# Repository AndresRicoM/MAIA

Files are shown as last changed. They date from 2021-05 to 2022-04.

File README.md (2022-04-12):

# MAIA

```
███╗   ███╗ █████╗ ██╗ █████╗
████╗ ████║██╔══██╗██║██╔══██╗
██╔████╔██║███████║██║███████║
██║╚██╔╝██║██╔══██║██║██╔══██║
██║ ╚═╝ ██║██║  ██║██║██║  ██║
╚═╝     ╚═╝╚═╝  ╚═╝╚═╝╚═╝  ╚═╝

. ,-"-.   ,-"-. ,-"-.   ,-"-. ,-"-.   ,
 X | | \ / | | X | | \ / | | X | | \ /
/ \| | |X| | |/ \| | |X| | |/ \| | |X|
   `-!-' `-!-"   `-!-' `-!-'   `-!-' `-

╔═╗┬┌┬┐┬ ┬  ╔═╗┌─┐┬┌─┐┌┐┌┌─┐┌─┐       ╔╦╗╦╔╦╗  ╔╦╗┌─┐┌┬┐┬┌─┐  ╦  ┌─┐┌┐
║  │ │ └┬┘  ╚═╗│  │├┤ ││││  ├┤   ───  ║║║║ ║   ║║║├┤  │││├─┤  ║  ├─┤├┴┐
╚═╝┴ ┴  ┴   ╚═╝└─┘┴└─┘┘└┘└─┘└─┘       ╩ ╩╩ ╩   ╩ ╩└─┘─┴┘┴┴ ┴  ╩═╝┴ ┴└─┘

```
Andres Rico - MIT Media Lab - aricom@mit.edu

Modular, low-cost, open source and portable bio reactor for bio sensor testing and deployment.

Ackowledgements:
Laura Gonzalez, Eyal Perry, David Kong, George Church, Joseph Jacobson.

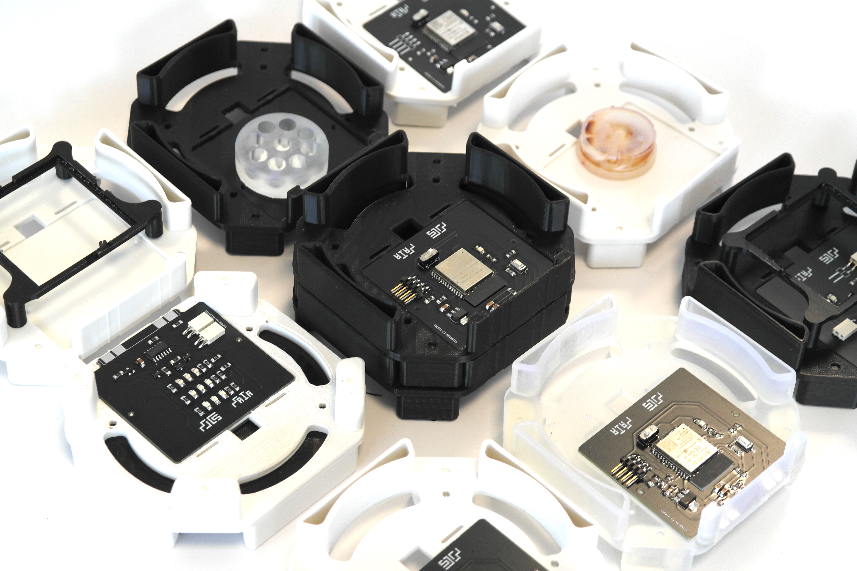
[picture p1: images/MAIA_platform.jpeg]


MAIA is a tool that inspires creativity by enhancing biosensor development for bottom-up citizen sensing applications.

The device is designed to be a tool that can allow for quick experimentation and testing of bio-sensor genetic circuits. The lab contributes to a growing ecosystem of the DIY-Bio movement. It provides a modular platform for experimental design and quick iteration based scientific development.

The device borrows characteristics from LEGO bricks to create easy to assemble and interchangeable components. Modules can be stacked and exchanged depending on function and experiment design. The project also integrates the vision of Arduino to motivate hacking and multi purpose use of the device. People can create modules and functionalities that are based on the main architecture design. The designs can be documented and distributed so that many have access to them. Lastly, the reactor brings to bio-reactor and bio-sensor development the benefits that mobile phones brought to computing.

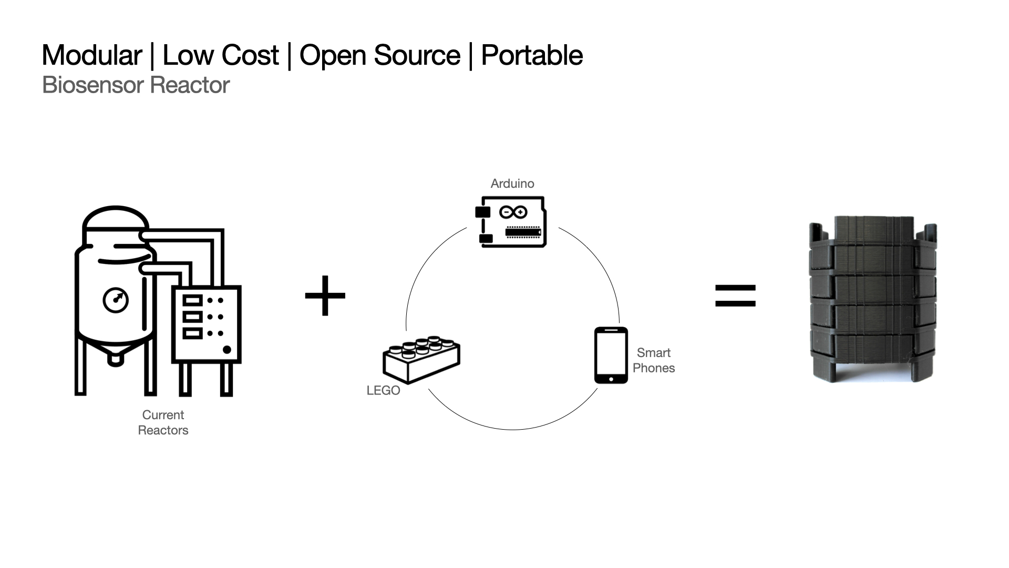
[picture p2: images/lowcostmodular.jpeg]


The device is easy to scale because its open source and low cost and can be used for multiple experiments as modules are created and designed specifically for each experiment. The current base structure allows for temperature, ventilation and light tuning.

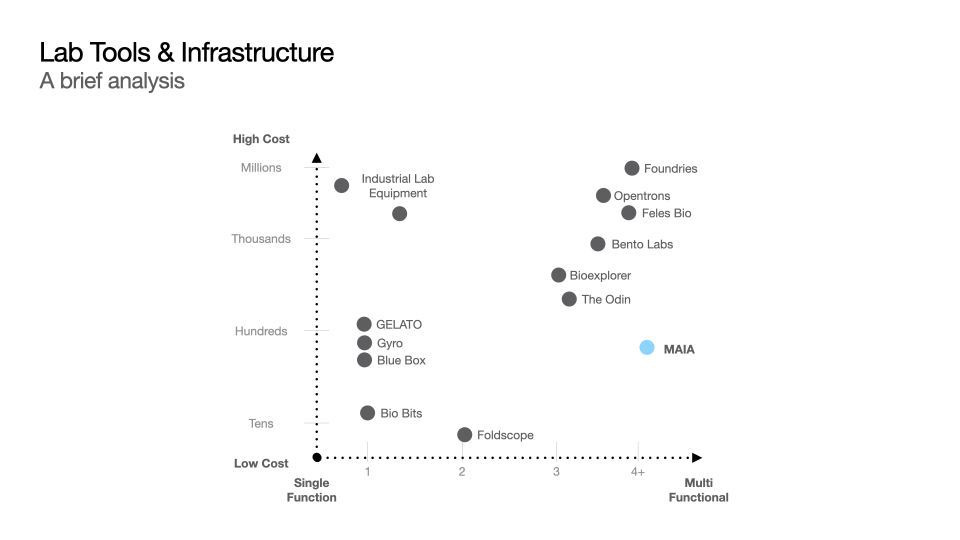
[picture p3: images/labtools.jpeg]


The device modularizes bio-reactor functions like, temperature and ventilation control to evaluate plasmid design and bio-sensing experiments. The top module of the device can be modified depending on the stimulation that we want to test. We can have experiments that stimulate cultures with sound, vibrations, light. 

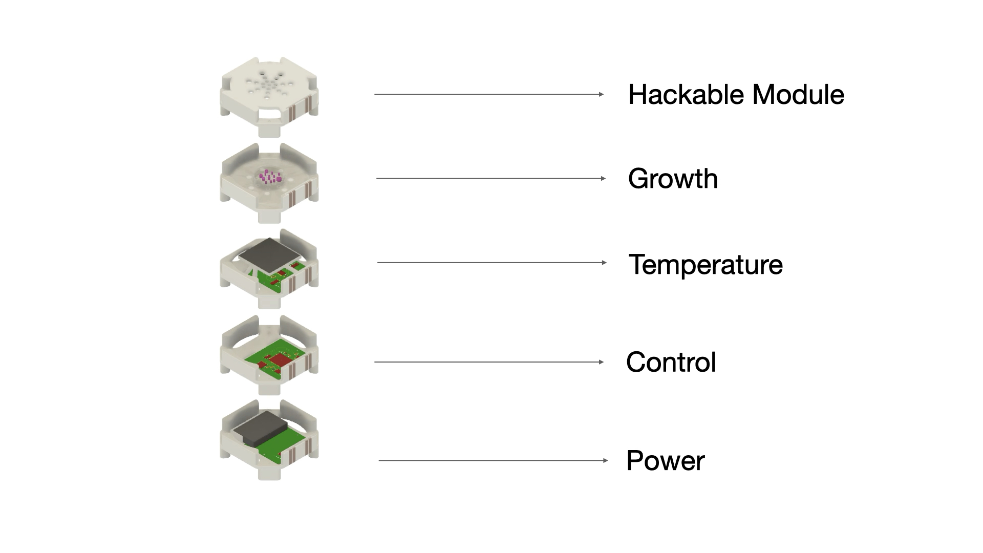
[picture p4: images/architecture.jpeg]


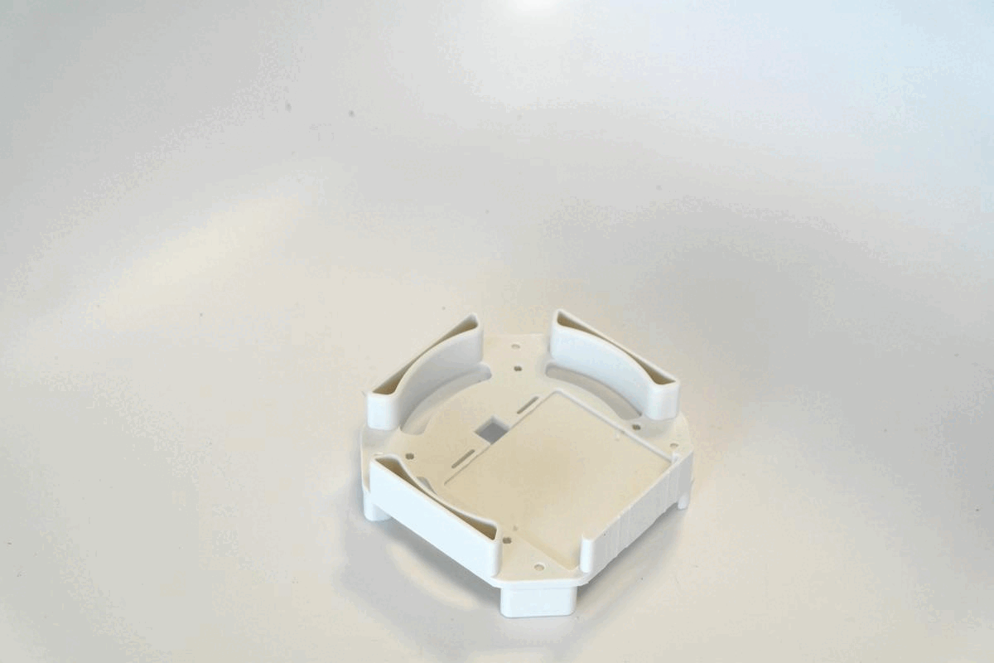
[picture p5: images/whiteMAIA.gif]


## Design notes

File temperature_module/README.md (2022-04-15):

MAIA Temperature Module

The module uses an epoxy thermistor and controls a peltier slip that is in contact with the bacterial culture.
The current version of the module only allows for heating up. The device cools down by deactivating the peltier and having the ambient temperature cool the device down. 

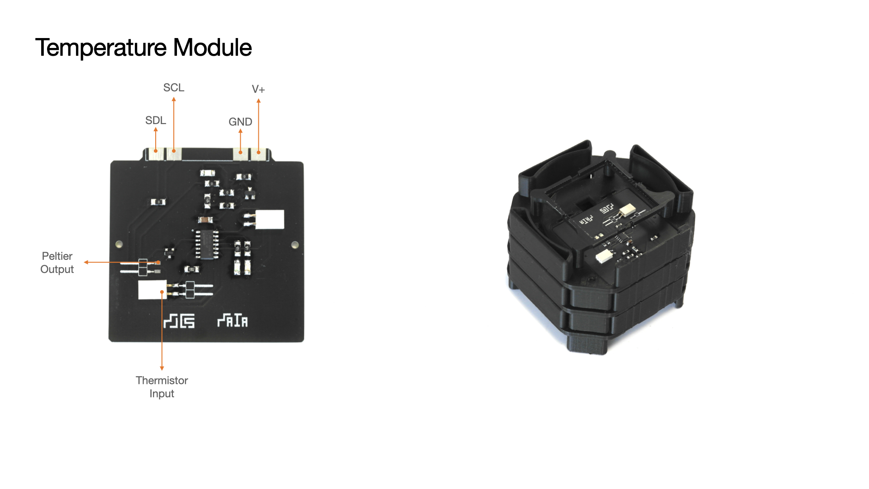
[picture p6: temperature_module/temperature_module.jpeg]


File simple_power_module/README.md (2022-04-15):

MAIA Power Module

The module connects to a 5V usb cable. It can also be used with Lipo batteries for portable operation.

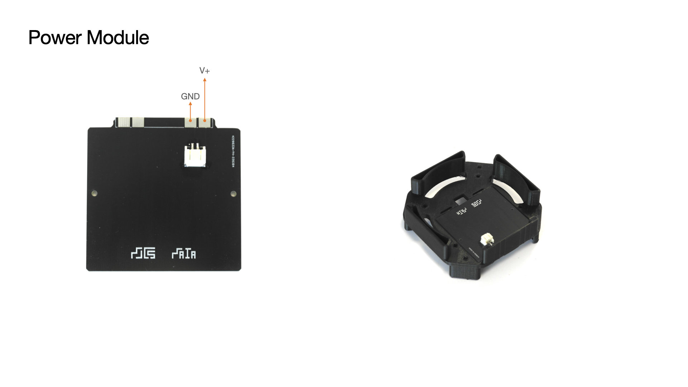
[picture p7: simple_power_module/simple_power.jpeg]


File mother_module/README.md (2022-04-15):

MAIA Mother Module

The Module enables WiFi and Bluetooth communication for the reactor. The module also controls messages sent to other modules and acts a central relay of infromation for the system.

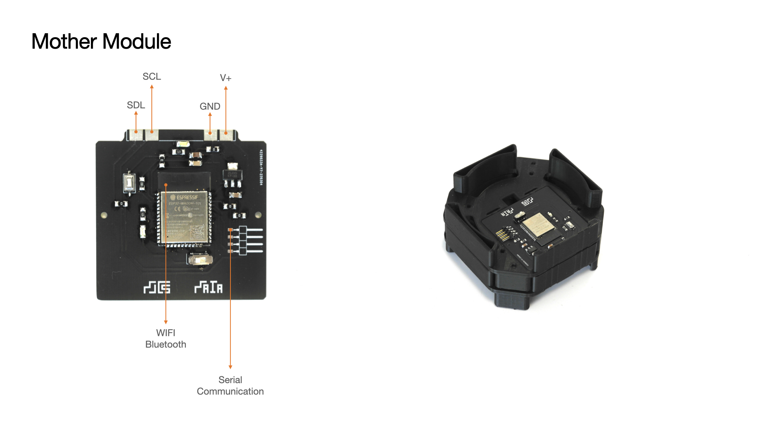
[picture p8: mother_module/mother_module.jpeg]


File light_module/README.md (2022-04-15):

MAIA Light Module

The Module can be used to stimulate bacteria in three different visible wavelengths (Red, Green, Blue).

It is important to note that the modules power anc communication lines are inverted because it is placed on the pcb slot that is at the lower section of the base module structure.

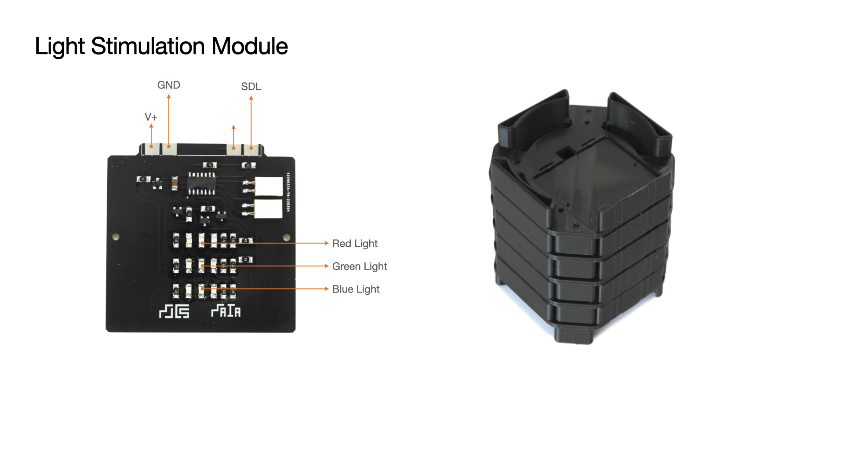
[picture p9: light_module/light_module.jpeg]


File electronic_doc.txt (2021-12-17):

Mother Board
I2C Address - 0

Temperature Board
Inputs - NTC Temperature Sensor
Outputs - Peltier, LED1, LED2

I2C Address - 3
Query with 1:
Returns Sensor and Peltier State

Query with 2:
Turns ON Peltier

Query with 3:
Turns OFF Peltier

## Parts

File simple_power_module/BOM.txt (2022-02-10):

- (1) JST Conn Header - S2B-PH-SM4-TB(LF)(SN)
- (1) JST Conn Header With Cable (Male)

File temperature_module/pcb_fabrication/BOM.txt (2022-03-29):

- (1) ATTINY 1614
- (5) 0 Ohm SMD 1206 Resistor
- (3) .5K SMD 1206 Resistor
- (1) 1uF SMD 1206 Capacitor
- (1) Green SMD LED
- (1) Blue SMD LED
- (1) Red SMD LED
- (1) 3.3V Regulator (ZLDO1117G33TA)
- (1) N Transistors
- (3) 2 pin Female horizontal headers
- (1) Peltier
- (1) NTC Epoxy Thermistor

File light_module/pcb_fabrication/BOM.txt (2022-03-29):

- (1) ATTINY 1614
- (7) 0 Ohm SMD 1206 Resistor
- (9) .5K SMD 1206 Resistor
- (1) 1uF SMD 1206 Capacitor
- (3) Green SMD LED (Best to only use 1 to not have heat problems)
- (3) Blue SMD LED
- (3) Red SMD LED
- (1) 3.3V Regulator (ZLDO1117G33TA)
- (3) N Transistors
- (2) 2 pin Female horizontal headers

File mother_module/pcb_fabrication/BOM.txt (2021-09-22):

- (1) ESP 32 WROOM
- (1) 10K SMD 1206 Resistor
- (2) .5K SMD 1206 Resistor
- (1) 1uF SMD 1206 Capacitor
- (1) .1uF SMD 1206 Capacitor
- (1) 10uF SMD 1206 Capacitor
- (1) Green SMD LED
- (1) Blue SMD LED
- (1) 3.3V Regulator (ZLDO1117G33TA)
- (1) Switch
- (1) Button

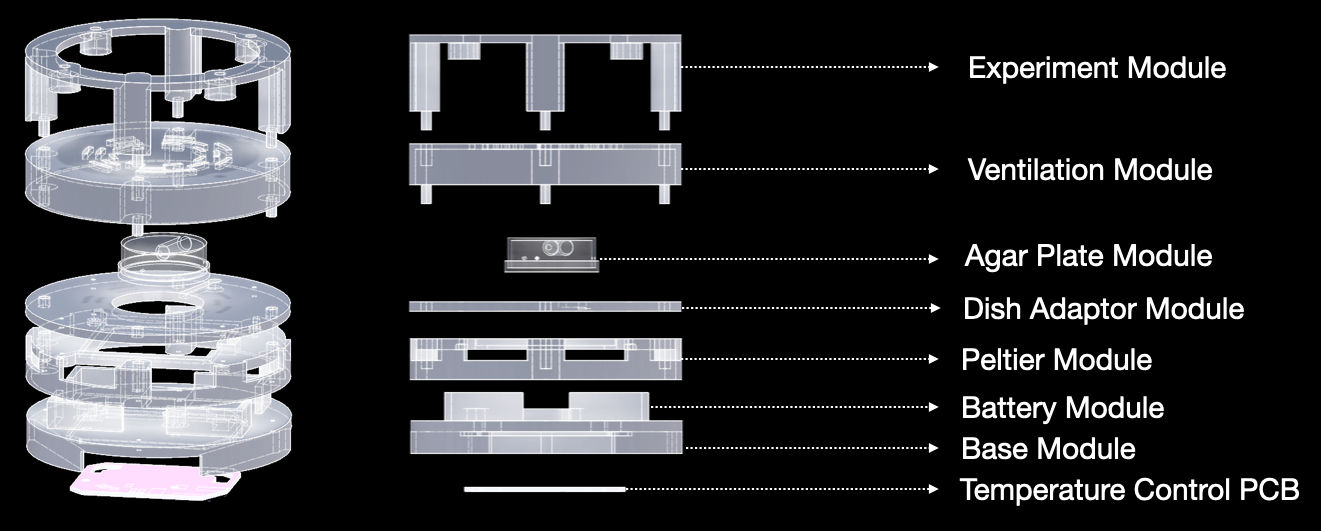
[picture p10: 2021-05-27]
images/parts.jpeg

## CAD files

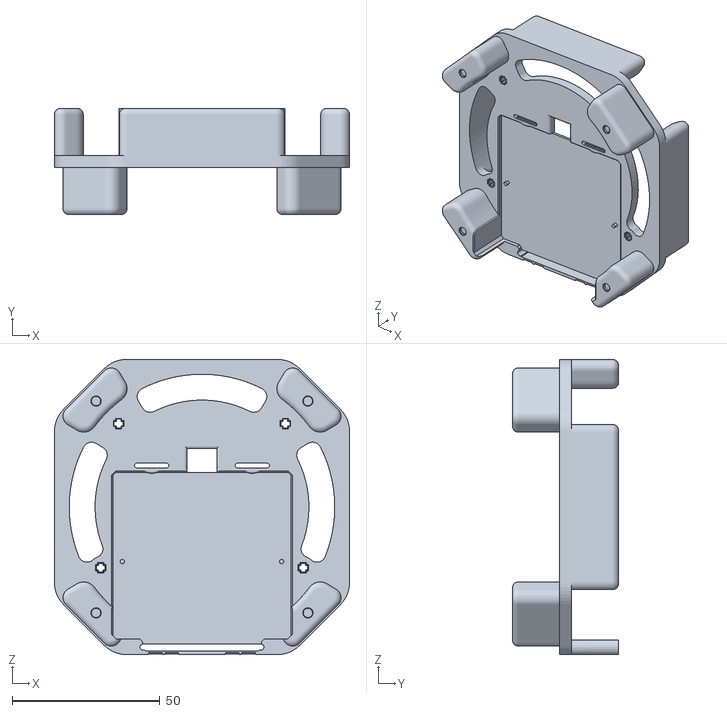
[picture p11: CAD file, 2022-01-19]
base_module/Modular_Base._Printing.stl
100.0 x 36.0 x 100.0

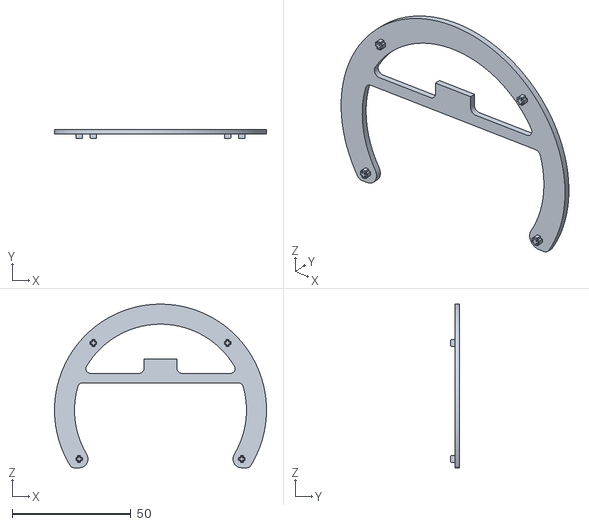
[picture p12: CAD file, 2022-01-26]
light_module/accesories/Ventilation-Light Lid.stl
89.4 x 4.00 x 69.0

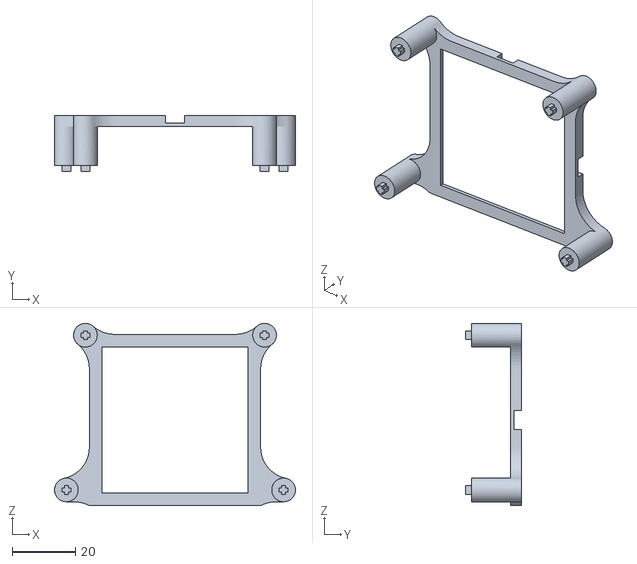
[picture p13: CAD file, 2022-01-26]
temperature_module/accesories/Peltier_Stand.stl
76.1 x 17.8 x 57.6

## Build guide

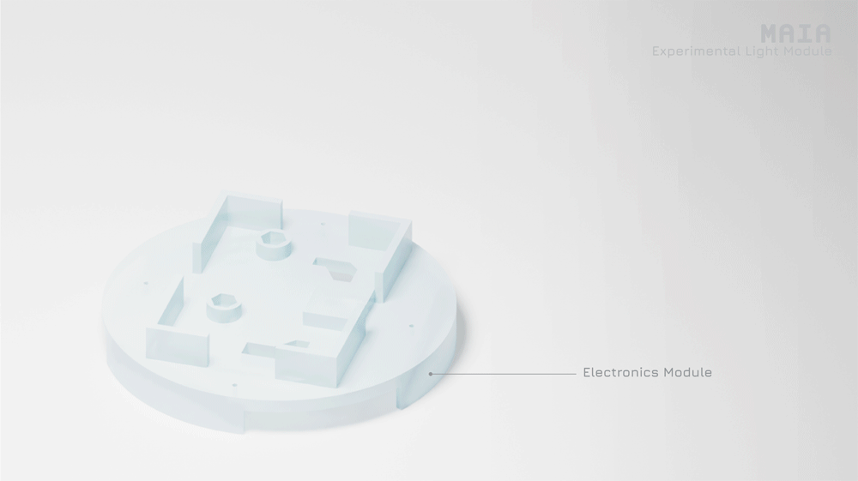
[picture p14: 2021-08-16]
images/light_module_assemble.gif

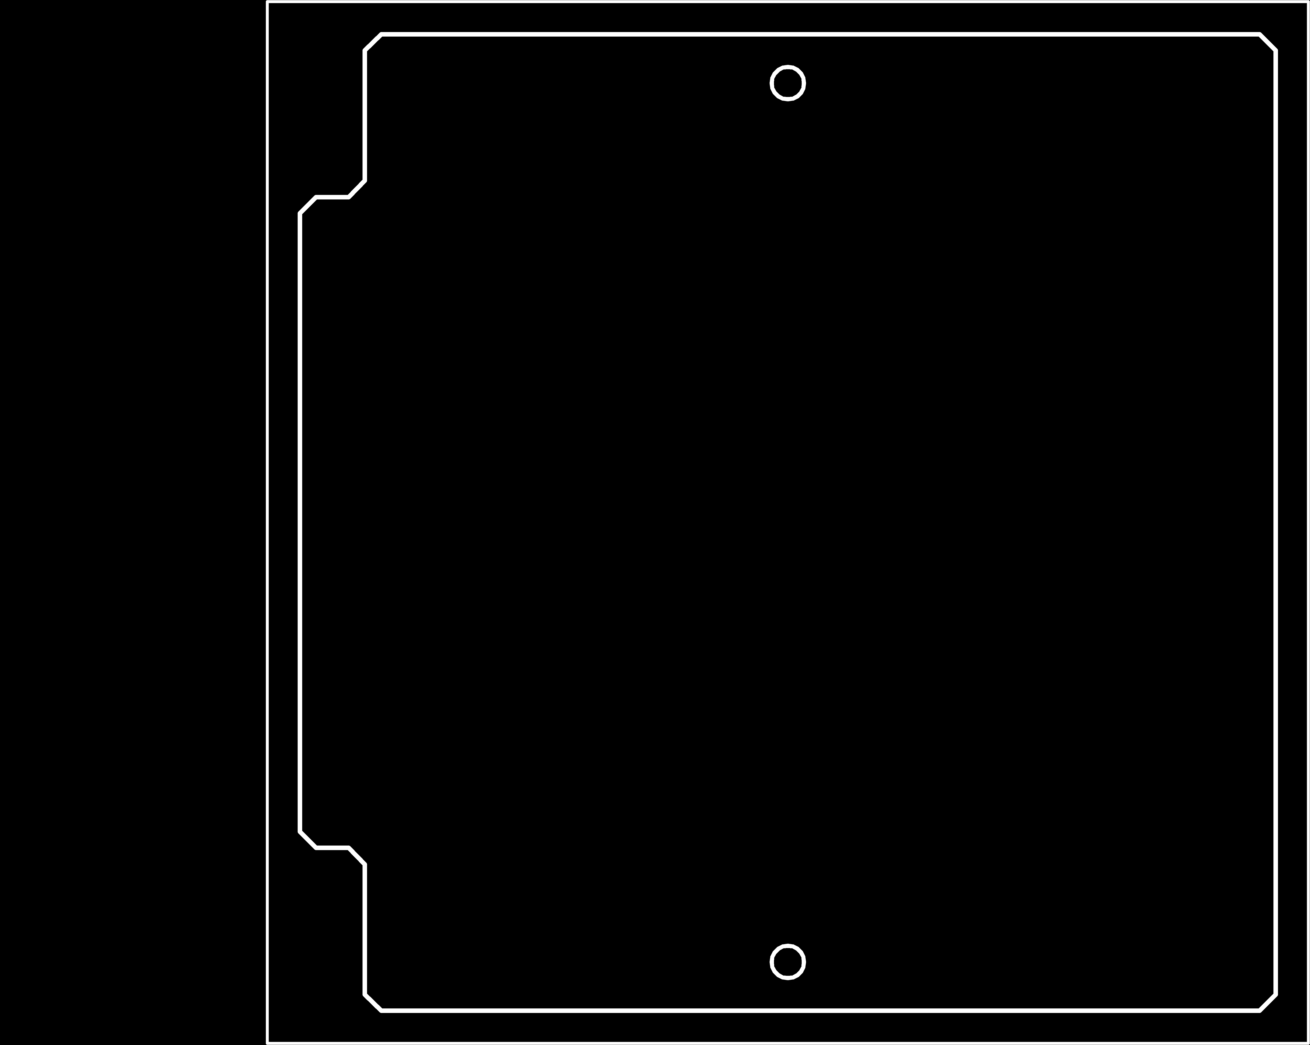
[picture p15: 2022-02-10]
light_module/pcb_fabrication/milling_files/maia_light_outline.png

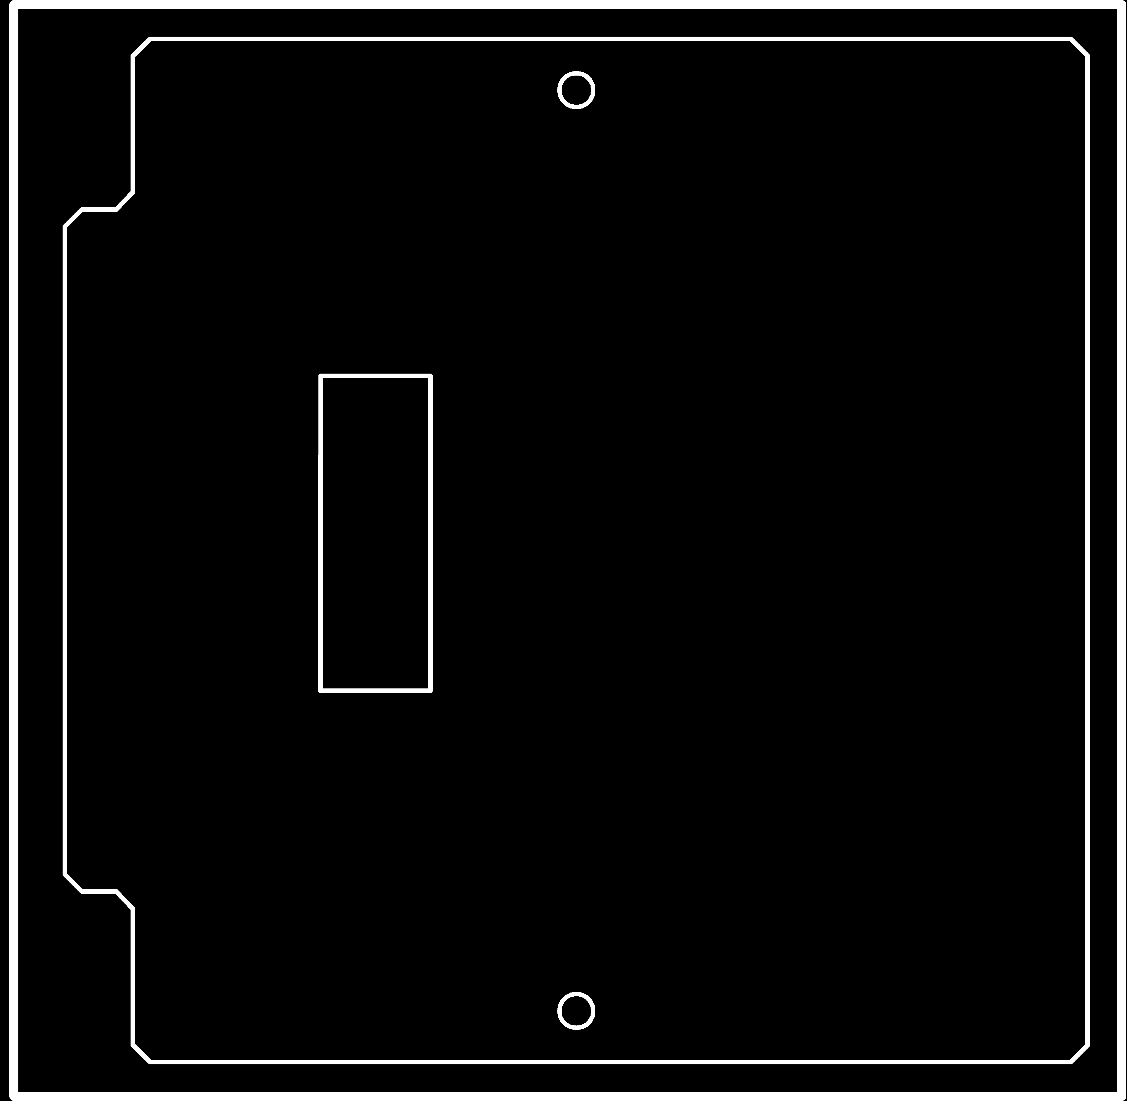
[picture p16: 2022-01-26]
mother_module/pcb_fabrication/milling_files/mother_board_outline.png

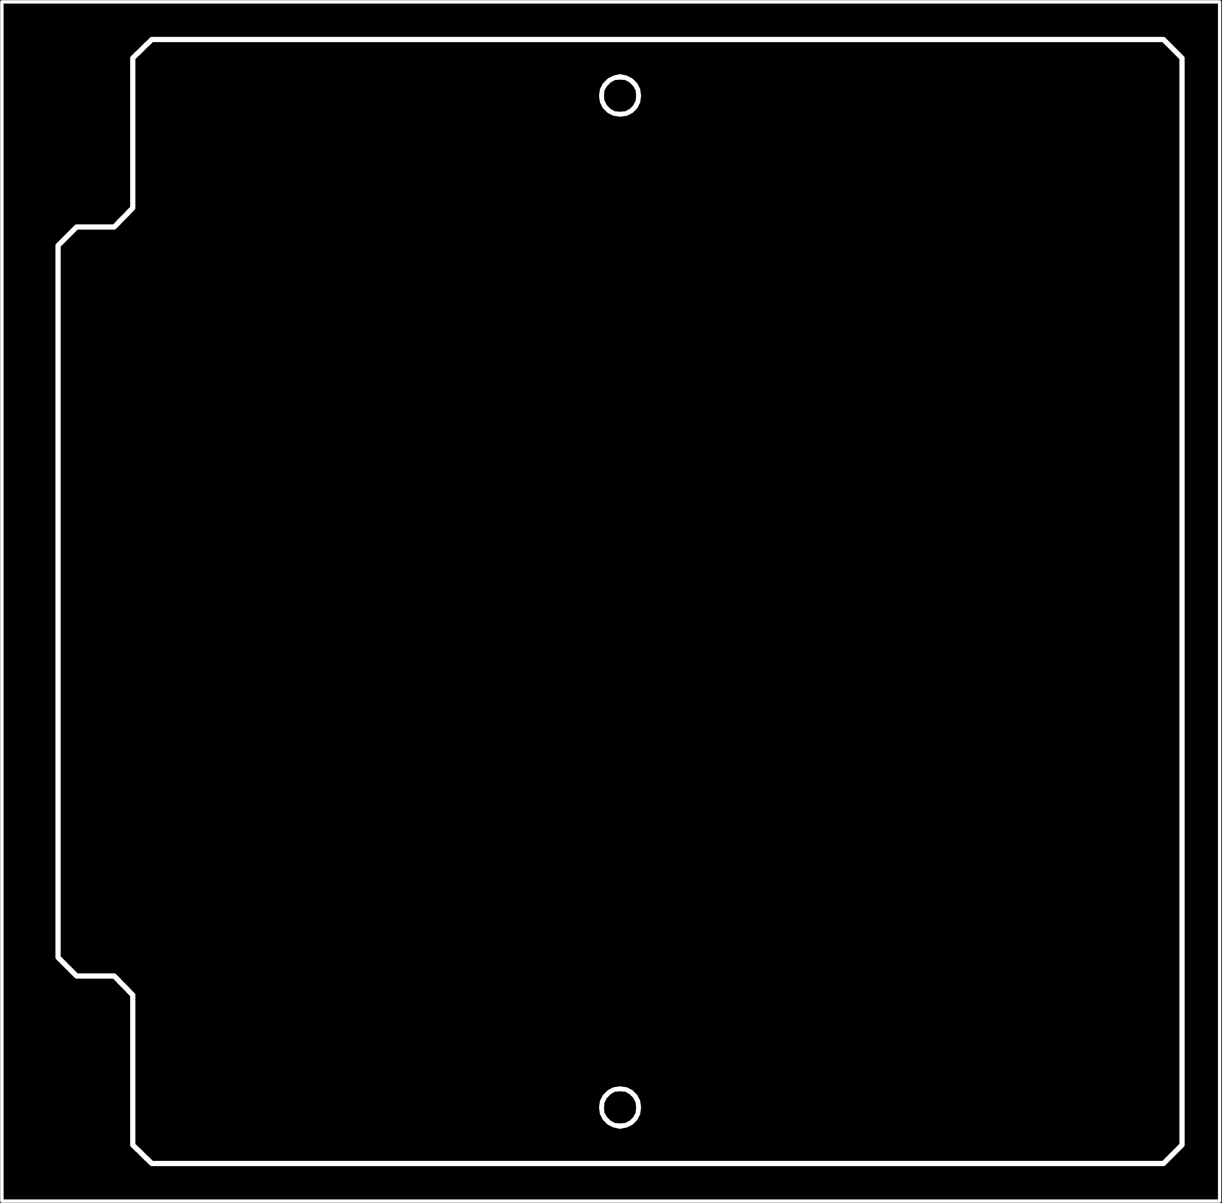
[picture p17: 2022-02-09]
temperature_module/pcb_fabrication/milling_files/maia_temperature_outline.png

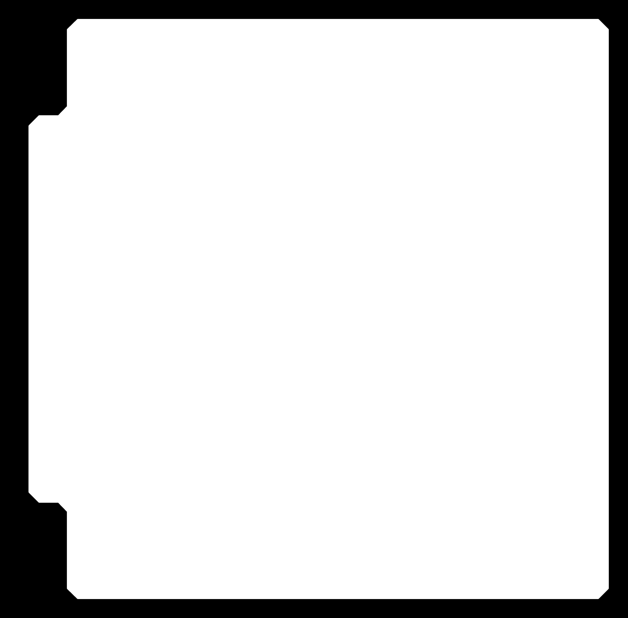
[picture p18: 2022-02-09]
temperature_module/pcb_fabrication/milling_files/maia_temperature_outline_out.png

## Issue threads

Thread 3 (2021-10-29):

Tight Fit - FormLabs

AndresRicoM, 2021-10-29:
Fittings from first print are very tight.  Need to make legs thinner so that modules can be stacked more easily.

AndresRicoM, 2022-01-19:
Have fixed tolerances! Base_Module now works great with a Form and a Prusa. The Prusa wil have a bit of a tighter fit with the PCBs but both are functional.

Closed 2022-01-19.

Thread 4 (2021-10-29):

Improve Temperature Board Fit

AndresRicoM, 2021-10-29:
Temperature board is hard to fit into the module. Need to add more space to fit board through the side peltier supports.

AndresRicoM, 2022-01-27:
Have fixed this with the new design of the base module. Temperature board now has an accessory tray for the peltier and fits nicely! #

Closed 2022-01-27.

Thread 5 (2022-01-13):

LiPo is not capable of powering mother board and peltier at the same time.

AndresRicoM, 2022-01-13:
I believe that a higher discharg rated battery could solve this issue. Meanwhile, connecting it to a 5V usb power supply does the trick quite well. A new power board design is needed for future generations.

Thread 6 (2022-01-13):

Base modules are still different.

AndresRicoM, 2022-01-13:
It would be great to have a base module that can be used to make all different modules. This would allow me to create a mold and cast out all of the components. Manufacturing would be more scalable and repeatable.

AndresRicoM, 2022-01-19:
Made a modular base file. This design can be used for many types of boards. It has 4 cross point inlets that can be used for inserting accessories depending on the application.  Module can be found here: https://github.com/AndresRicoM/MAIA/blob/main/MARKII/modular_base/Modular_Base._Printing.stl

Closed 2022-01-19.

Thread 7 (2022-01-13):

2 way I2c esp32 communication

AndresRicoM, 2022-01-13:
The ESP32 and Wire.h library do not allow for two way master/slave communication. This is needed so that the ESP is able to gather all of the external modules' states. I've implemented one way communication and we can still have good control of variables but adding two way communication will be essential for live data monitoring and the GUI.

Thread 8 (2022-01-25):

LED Board Does not Connect All LEDs to pwr.

AndresRicoM, 2022-01-25:
Have fixed eagle file but not png traces nor milling gcode.

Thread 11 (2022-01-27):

EEPROM value save for temperature board.

AndresRicoM, 2022-01-27:
Need to save current value to EEPROM so that module knows last value sent to it. This is helpful in case of any power outages or fluctuations.

AndresRicoM, 2022-02-01:
Modified code so that everytime the temperature module receives a new command, it stores the value on internal memory. This helps out to counter effects of power outages.

Closed 2022-02-01.

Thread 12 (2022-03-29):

Light Board Burns AGAr plate

AndresRicoM, 2022-03-29:
The light board creates too much heat and touches the agar plate when incubating. It's likely that only using one LED to stimulate will solve this issue.  Smaller agar plates could also help to avoid the culture being in direct contact with the light PCB board.

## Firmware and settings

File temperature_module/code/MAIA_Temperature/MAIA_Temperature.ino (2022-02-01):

/*
      
      ███╗   ███╗ █████╗ ██╗ █████╗
      ████╗ ████║██╔══██╗██║██╔══██╗
      ██╔████╔██║███████║██║███████║
      ██║╚██╔╝██║██╔══██║██║██╔══██║
      ██║ ╚═╝ ██║██║  ██║██║██║  ██║
      ╚═╝     ╚═╝╚═╝  ╚═╝╚═╝╚═╝  ╚═╝
      
      ╔═╗┬┌┬┐┬ ┬  ╔═╗┌─┐┬┌─┐┌┐┌┌─┐┌─┐       ╔╦╗╦╔╦╗  ╔╦╗┌─┐┌┬┐┬┌─┐  ╦  ┌─┐┌┐
      ║  │ │ └┬┘  ╚═╗│  │├┤ ││││  ├┤   ───  ║║║║ ║   ║║║├┤  │││├─┤  ║  ├─┤├┴┐
      ╚═╝┴ ┴  ┴   ╚═╝└─┘┴└─┘┘└┘└─┘└─┘       ╩ ╩╩ ╩   ╩ ╩└─┘─┴┘┴┴ ┴  ╩═╝┴ ┴└─┘

      Modular, low-cost and portable bio reactor. 

      Temperature Module Firmware.
      Andres Rico - aricom@mit.edu
 */

#include <Wire.h> //I2C Communication
#include <EEPROM.h> //EEPROM access library.

//Definitions for thermistor temperature option. 
#define SERIESRESISTOR 10000
#define THERMISTORPIN 3
#define TEMPERATURENOMINAL 25
#define BCOEFFICIENT 3950   
#define THERMISTORNOMINAL 10000

int led1 = 9; //Blue LED
int led2 = 8; //Red LED
int peltier = 1; //Peltier pin. 

int x = 0; //Variable for storing incoming i2c message. 

float temp_average = 0; //Float for stroing temperature sensoir value. 

void setup() {
  // put your setup code here, to run once:

  Serial.begin(115200);
  Serial.println("Hello MAIA Temperature Module");
  
  pinMode(led1, OUTPUT);
  pinMode(led2, OUTPUT);
  pinMode(peltier, OUTPUT);

  digitalWrite(led1, LOW);
  digitalWrite(led2, LOW);
  digitalWrite(peltier, LOW);

  x = EEPROM.read(0); //Check eproom to turn on last value of temperature that was sent. Essential for when power fluctuates on chip.

  Wire.begin(3);
  Wire.onReceive(receiveEvent);
  Serial.println("Ready To Begin!");
}

void loop() {
  //Serial.println(Wire.read());

  while (temp_average < x) { //Peltier will heat up anytime that temperature is below target. 
  
    digitalWrite(peltier, HIGH);
    digitalWrite(led2, HIGH); //Red led on for heating up. 
    digitalWrite(led1, LOW);
    get_temperature();
    
  }
  digitalWrite(peltier, LOW);
  digitalWrite(led1, HIGH); //Blue led on when temperature is correct or reactor is cooling down. 
  digitalWrite(led2, LOW);
  get_temperature();
  
}

void receiveEvent(int bytes) { //Runs when i2c receives message. 
  
  x = Wire.read(); //Reads i2c message. 
  Serial.print("Received Target Temperature of: ");
  Serial.println(x);

  EEPROM.write(0,x); //Sets new value on internal memory in case module restarts. 
}

void get_temperature() { //Oversamples NTC analog pin to get average of temperature. 

  //Thermistor Temperature
  temp_average = 0;
  for (int i =0; i < 50 ; i++) { //50 samples per average. 

    float therm_reading;
 
    therm_reading = analogRead(THERMISTORPIN);
   
    // convert the value to resistance
    therm_reading = (1023 / therm_reading)  - 1;     // (1023/ADC - 1) 
    therm_reading = SERIESRESISTOR / therm_reading;  // 10K / (1023/ADC - 1)
  
    float thermTemp;
    thermTemp = therm_reading / THERMISTORNOMINAL;     // (R/Ro)
    thermTemp = log(thermTemp);                  // ln(R/Ro)
    thermTemp /= BCOEFFICIENT;                   // 1/B * ln(R/Ro)
    thermTemp += 1.0 / (TEMPERATURENOMINAL + 273.15); // + (1/To)
    thermTemp = 1.0 / thermTemp;                 // Invert
    thermTemp -= 273.15; // convert absolute temp to C

    temp_average = temp_average + thermTemp;
    
  }

  temp_average = temp_average / 50; //Define temperature value. 
  Serial.print("Current Culture Temperature: ");
  Serial.println(temp_average);
  
}

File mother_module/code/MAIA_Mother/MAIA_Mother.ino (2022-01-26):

/*
      
      ███╗   ███╗ █████╗ ██╗ █████╗
      ████╗ ████║██╔══██╗██║██╔══██╗
      ██╔████╔██║███████║██║███████║
      ██║╚██╔╝██║██╔══██║██║██╔══██║
      ██║ ╚═╝ ██║██║  ██║██║██║  ██║
      ╚═╝     ╚═╝╚═╝  ╚═╝╚═╝╚═╝  ╚═╝
      
      ╔═╗┬┌┬┐┬ ┬  ╔═╗┌─┐┬┌─┐┌┐┌┌─┐┌─┐       ╔╦╗╦╔╦╗  ╔╦╗┌─┐┌┬┐┬┌─┐  ╦  ┌─┐┌┐
      ║  │ │ └┬┘  ╚═╗│  │├┤ ││││  ├┤   ───  ║║║║ ║   ║║║├┤  │││├─┤  ║  ├─┤├┴┐
      ╚═╝┴ ┴  ┴   ╚═╝└─┘┴└─┘┘└┘└─┘└─┘       ╩ ╩╩ ╩   ╩ ╩└─┘─┴┘┴┴ ┴  ╩═╝┴ ┴└─┘

      Modular, low-cost and portable bio reactor. 

      Mother Module Firmware.
      Andres Rico - aricom@mit.edu
 */

#include <WiFi.h>
#include <Wire.h>
#include <WiFiUdp.h>


//WIFI Variables
const char* ssid = "MIT"; //Change accordingly to connect to a WIFi network. 
const char* password = "";

//UDP Variables
WiFiUDP Udp; //UDP instance

char packetBuffer[255]; //Buffer to store UDP packets. 

unsigned int port = 1206; //Port chosen arbitrarily. 

///////Includes main modules addresses. Add hacked modules here. 

int temperature_board = 3;  //T[Data]
int power_board = 4;        //P[Data]
int light_board = 5;        //L[Data]

int led = 32; //Debugging Green LED.

int desired_temperature = 0; //Desired temperature in Celcius. Current version's minimum temp will be ambient temperature. 

void setup() {
  // put your setup code here, to run once:
  Serial.begin(115200);
  Serial.print("Hello, I'm MAIA!");
  
  //WiFi.mode(WIFI_STA); //Optional
  WiFi.begin(ssid, password);
  // Check wi-fi is connected to wi-fi network
  while (WiFi.status() != WL_CONNECTED) {
  delay(1000);
  Serial.print(".");
  }
  Serial.println("");
  Serial.println("WiFi connected successfully");
  Serial.print("Got IP: ");
  Serial.println(WiFi.localIP());  //Show ESP32 IP on serial

  Wire.begin();
  Serial.println("Enabled I2C Communication @ Address: 0x00");

  Udp.begin(port);
  Serial.print("Opened UDP Communication @ Port: ");
  Serial.println(port);
  
  pinMode(led, OUTPUT);  
  

}

void loop() {
  //// put your main code here, to run repeatedly:
  getUDP();
  
  
}

void getUDP() {
  
  int packetSize = Udp.parsePacket();

  if (packetSize) {

    Serial.print("Received packet of size ");
    Serial.println(packetSize);
    Serial.print("From ");
    IPAddress remoteIp = Udp.remoteIP();
    Serial.print(remoteIp);
    Serial.print(", port ");
    Serial.println(Udp.remotePort());
    
    // read the packet into packetBufffer
    int len = Udp.read(packetBuffer, 255);
    
    if (len > 0) {
      packetBuffer[len] = 0;
    }

    Serial.println("Contents:");
    Serial.println(packetBuffer);

    if (packetBuffer[0] == 'T') { //Checks if Commans is comming to change temperature.
      
      Serial.println("Received New Temperature Command");
      desired_temperature = ((packetBuffer[1] - '0') * 10) + ((packetBuffer[2] - '0'));

      Serial.print("New Desired Temperature Set @ ");
      Serial.println(desired_temperature);
      
      digitalWrite(led, HIGH);
      int message = desired_temperature;
      Wire.beginTransmission(temperature_board);
      Wire.write(message);
      Wire.endTransmission();
      delay(500);
      digitalWrite(led, LOW);
      delay(500);
      
    }

    else if (packetBuffer[0] == 'L') { //Checks if command is comming to change Light.
      
      Serial.println("Received New Light Command");

      switch (packetBuffer[1] - '0') { 
        
        case 1: { //Red Light
          Serial.println("Turning Red Light On");
          digitalWrite(led, HIGH);
          int message = packetBuffer[1] - '0';
          Wire.beginTransmission(light_board);
          Wire.write(message);
          Wire.endTransmission();
          delay(500);
          digitalWrite(led, LOW);
          delay(500);
          }
          break;
          

        case 2: { //Green Light
          Serial.println("Turning Green Light On");
          digitalWrite(led, HIGH);
          int message = packetBuffer[1] - '0';
          Wire.beginTransmission(light_board);
          Wire.write(message);
          Wire.endTransmission();
          delay(500);
          digitalWrite(led, LOW);
          delay(500);
          }
          break;
        

        case 3: { //Blue Light
          Serial.println("Turning Blue Light On");
          digitalWrite(led, HIGH);
          int message = packetBuffer[1] - '0';
          Wire.beginTransmission(light_board);
          Wire.write(message);
          Wire.endTransmission();
          delay(500);
          digitalWrite(led, LOW);
          delay(500);
          }
          break;

        case 4: { //White Light
          Serial.println("Turning White Light On");
          digitalWrite(led, HIGH);
          int message = packetBuffer[1] - '0';
          Wire.beginTransmission(light_board);
          Wire.write(message);
          Wire.endTransmission();
          delay(500);
          digitalWrite(led, LOW);
          delay(500);
          }
          break;

         case 5: { //Lights Off
          Serial.println("Turning Lights Off");
          digitalWrite(led, HIGH);
          int message = packetBuffer[1] - '0';
          Wire.beginTransmission(light_board);
          Wire.write(message);
          Wire.endTransmission();
          delay(500);
          digitalWrite(led, LOW);
          delay(500);
          }
          break;
      }    
    }

    else {
      Serial.println("Packet Error");
    }
  }
}

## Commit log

2021-05-27 added stl files
    [PCBMount.stl, PELTMount.stl, agar_plate.stl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]
2021-05-27 added speaker files
    [speaker_driver_mount.stl, speaker_experimental_module.stl]
2021-05-27 added temperature control code
2021-06-04 added transistor board design
2021-06-04 added liquid culture stl
    [agar_cavity_40mm.dxf, liquid_culture_plate.stl]
2021-08-14 Added light module components
    [Fluidics_Adapter.stl]
2021-08-15 Added assembly diagram
2021-09-20 Added updates on power module
2021-09-21 mother board design
    [agar_cavity_40mm.dxf, agar_plate.stl, agar_plate_lid.stl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]
2021-09-22 updated new mother board with antenna hole and button
2021-09-22 stuffed mother board
2021-09-22 adding regulator part number
2021-10-01 added simple power board
2021-12-17 added progress on electronics and prototypes.
2021-12-17 added modules assembled and turned on images!
2022-01-12 added udp communication for temperature tests.
2022-01-19 added modular base stl
    [Modular_Base._Printing.stl]
2022-01-21 added light stimulation PCB
2022-01-23 added cutting files for light PCB
2022-01-26 added files for light and temperature board.
    [Peltier_Stand.stl, Ventilation-Light Lid.stl]
2022-01-26 arranged module building documents (fab, code, accesories)
    [Modular_Base._Printing.stl]
2022-01-26 fixed mother module led output pin.
    [Modular_Base._Printing.stl, Peltier_Stand.stl, Ventilation-Light Lid.stl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]
2022-01-27 light module saves last value on eeprom power outages safety
2022-02-01 Commented code and added internal memory registry of temperature.
2022-02-01 organized first prototype folders
    [Fluidics_Adapter.stl, speaker_driver_mount.stl, speaker_experimental_module.stl]
2022-02-01 organized folders
    [Fluidics_Adapter.stl, Modular_Base._Printing.stl, Peltier_Stand.stl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]
2022-02-03 added fixed mother board schematic and gcode
2022-02-09 temperature board pcb fabrication docs
2022-02-10 added light board traces and gcode
2022-02-10 added BOM for simple power module
2022-02-11 added 3d printing files for base module
2022-03-03 gerber files for light
2022-03-03 added gerber files for temperature pcb
2022-03-03 added gerber files for mother board
2022-03-03 added gerber file for simple power board
2022-03-29 Update BOM.txt
    added components to light BOM
2022-04-15 simple power module
2022-04-15 temperature module readme
